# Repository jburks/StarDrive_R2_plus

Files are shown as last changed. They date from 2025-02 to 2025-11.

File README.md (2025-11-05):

# StarDrive_R2_plus
StarBoard SCSI Drive attachment with real-time clock

## Mini-FAQ:

### What is it?

StarDrive R2+ is an upgraded version of Chris "Crispy" Brenner's original reverse-engineered remake of the Microbotics StarDrive for their
StarBoard 2 expansion module for the Amiga 1000.

### Where can I get it?

This product is still in development. All files necessary for making your own will be here and links to assembled boards for sale will be
placed here when available.

### What's the status?

The original project has been converted to KiCAD and ports have been placed as accurately as possible using the materials still available
from Crispy's original design. Additional footprints for the slightly more available PCF8573T and footprints for a microcontroller and modern RTC are
WIP.

### What's this about an upgrade?

The original StarDrive uses two components that are no longer in production: the AM5380 SCSI interface controller; and the PCF8573P real-time clock.
Direct replacements are not known to be available for either, so StarBoard R2+ is planned to contain a microcontroller capable of emulating the PCF8573
so that a modern, easy to source solution is available. A substitute for the AM5380 has not been identified.

### How can I help?

The project would benefit from a modified StarBoard 2 driver that modifies the I2C code to talk to a modern RTC directly so that a PCF8573 or a
microcontroller that emulates one is not necessary.

## Board renderings

### Front:

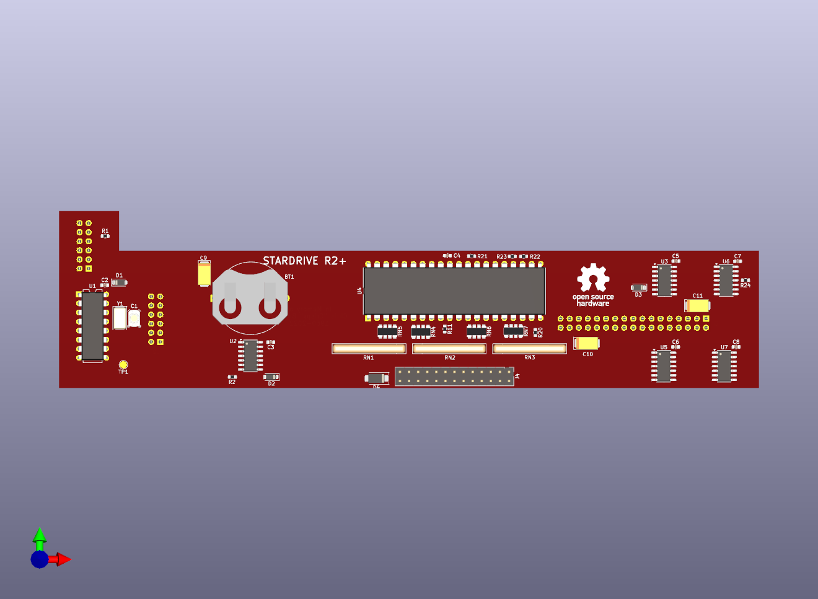
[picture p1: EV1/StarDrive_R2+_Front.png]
StarDrive R2+ Front


### Back:

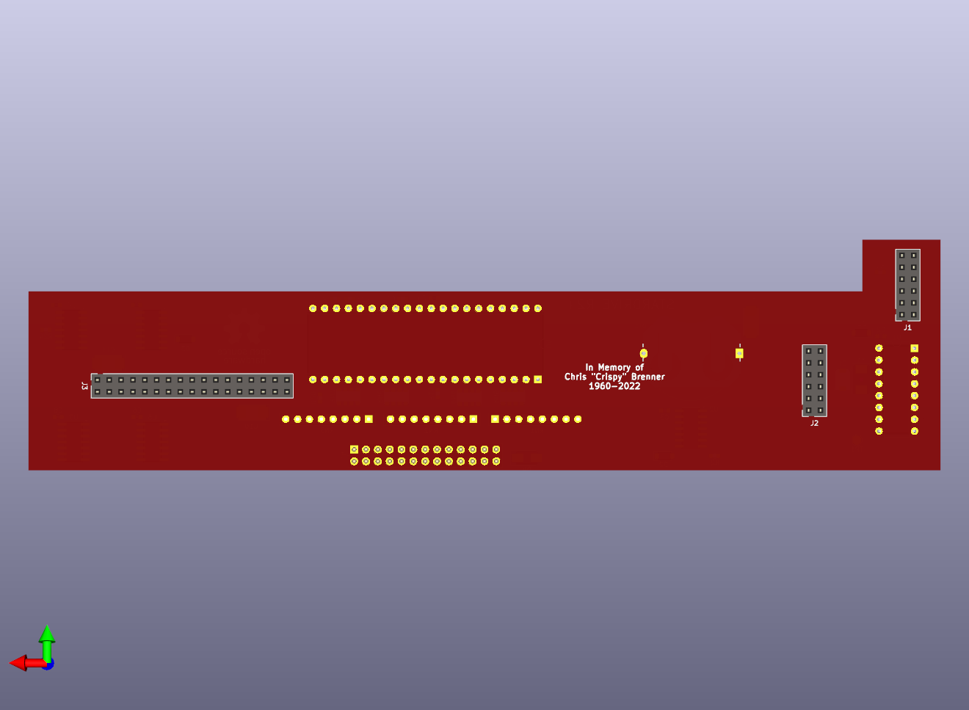
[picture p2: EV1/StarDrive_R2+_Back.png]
StarDrive R2+ Back


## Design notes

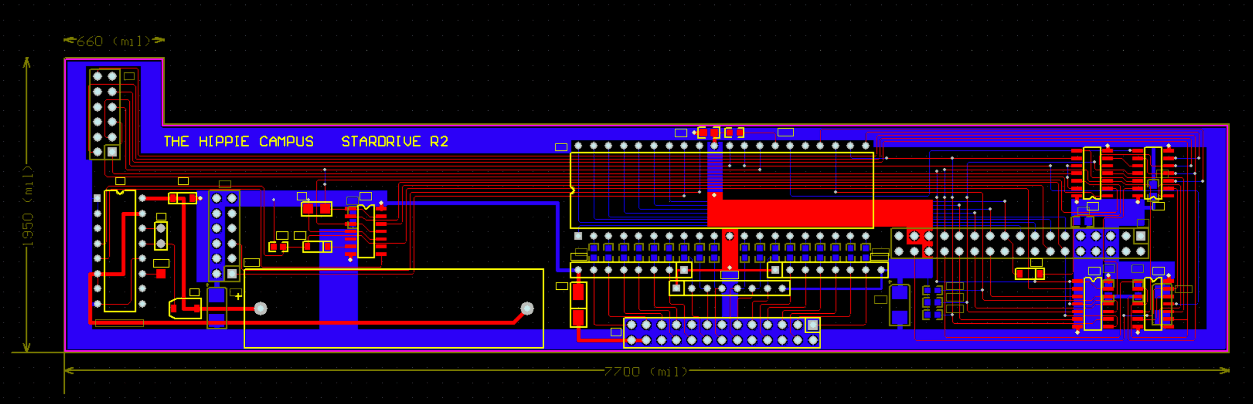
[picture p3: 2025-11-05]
X2_X2+_Overlay.gif

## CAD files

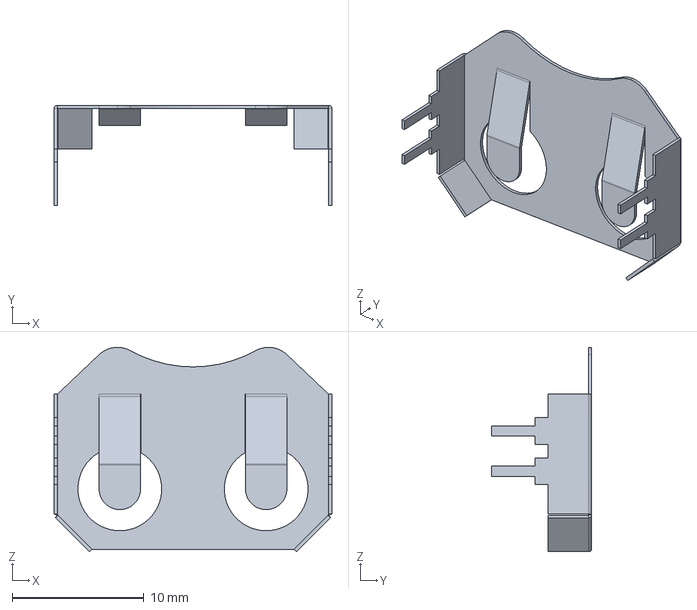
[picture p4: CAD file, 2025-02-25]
parts/3dmodels/c-bat-hld-001-thm-tr-b-3d.stp
21.1 x 7.62 x 15.5 mm

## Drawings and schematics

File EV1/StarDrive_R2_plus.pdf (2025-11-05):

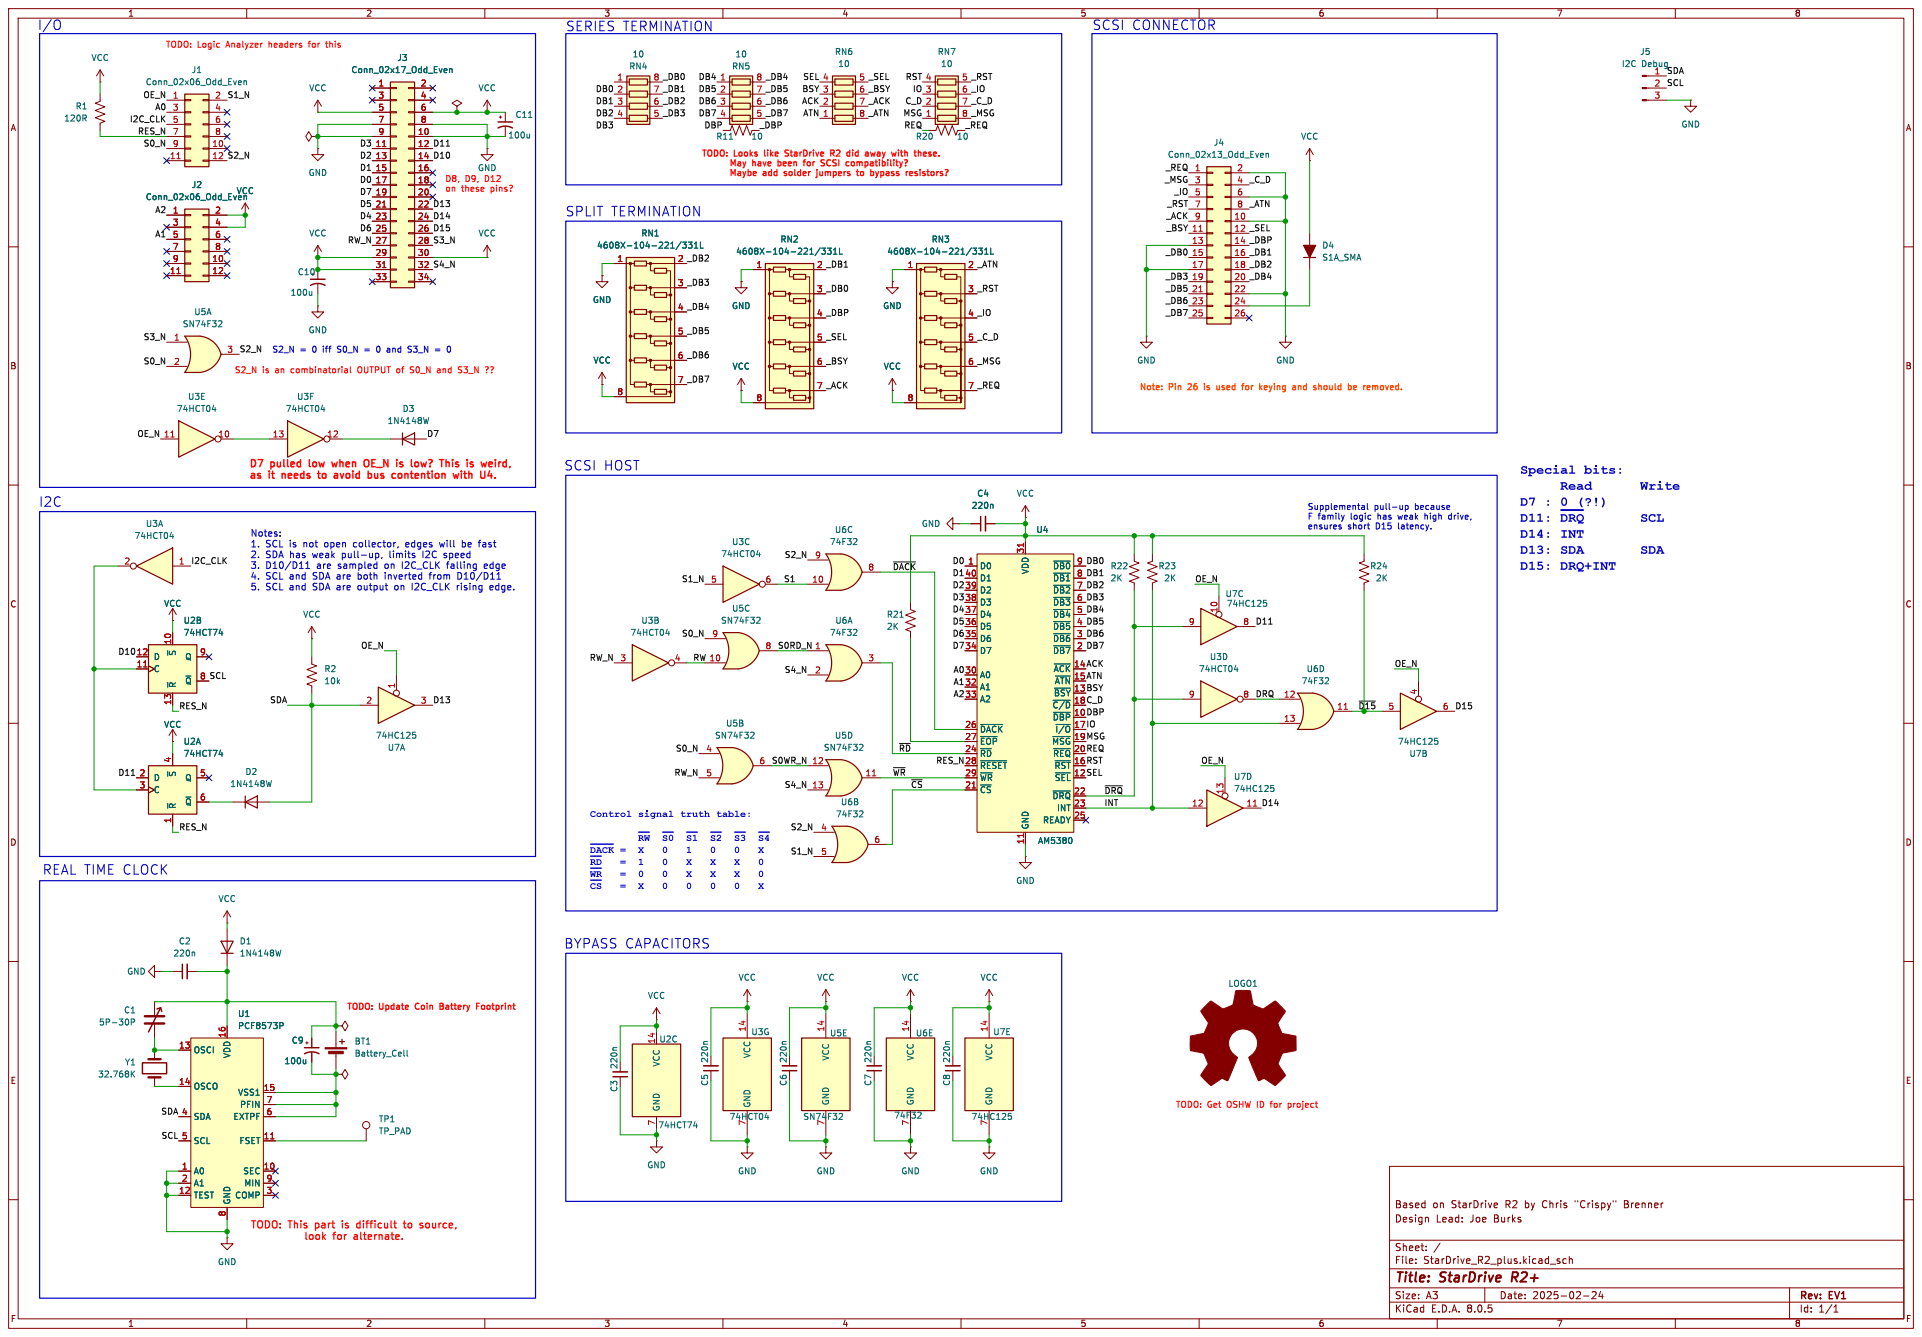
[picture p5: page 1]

TODO: Logic Analyzer headers for this

TODO: Looks like StarDrive R2 did away with these. May have been for SCSI compatibility?

4. SCL and SDA are both inverted from D10/D11
5. SCL and SDA are output on I2C_CLK rising edge.

Control signal truth table: ~{RW}~{S0}~{S1}~{S2}~{S3}~{S4}

TODO: Update Coin Battery Footprint

TODO: Get OSHW ID for project

TODO: This part is difficult to source,

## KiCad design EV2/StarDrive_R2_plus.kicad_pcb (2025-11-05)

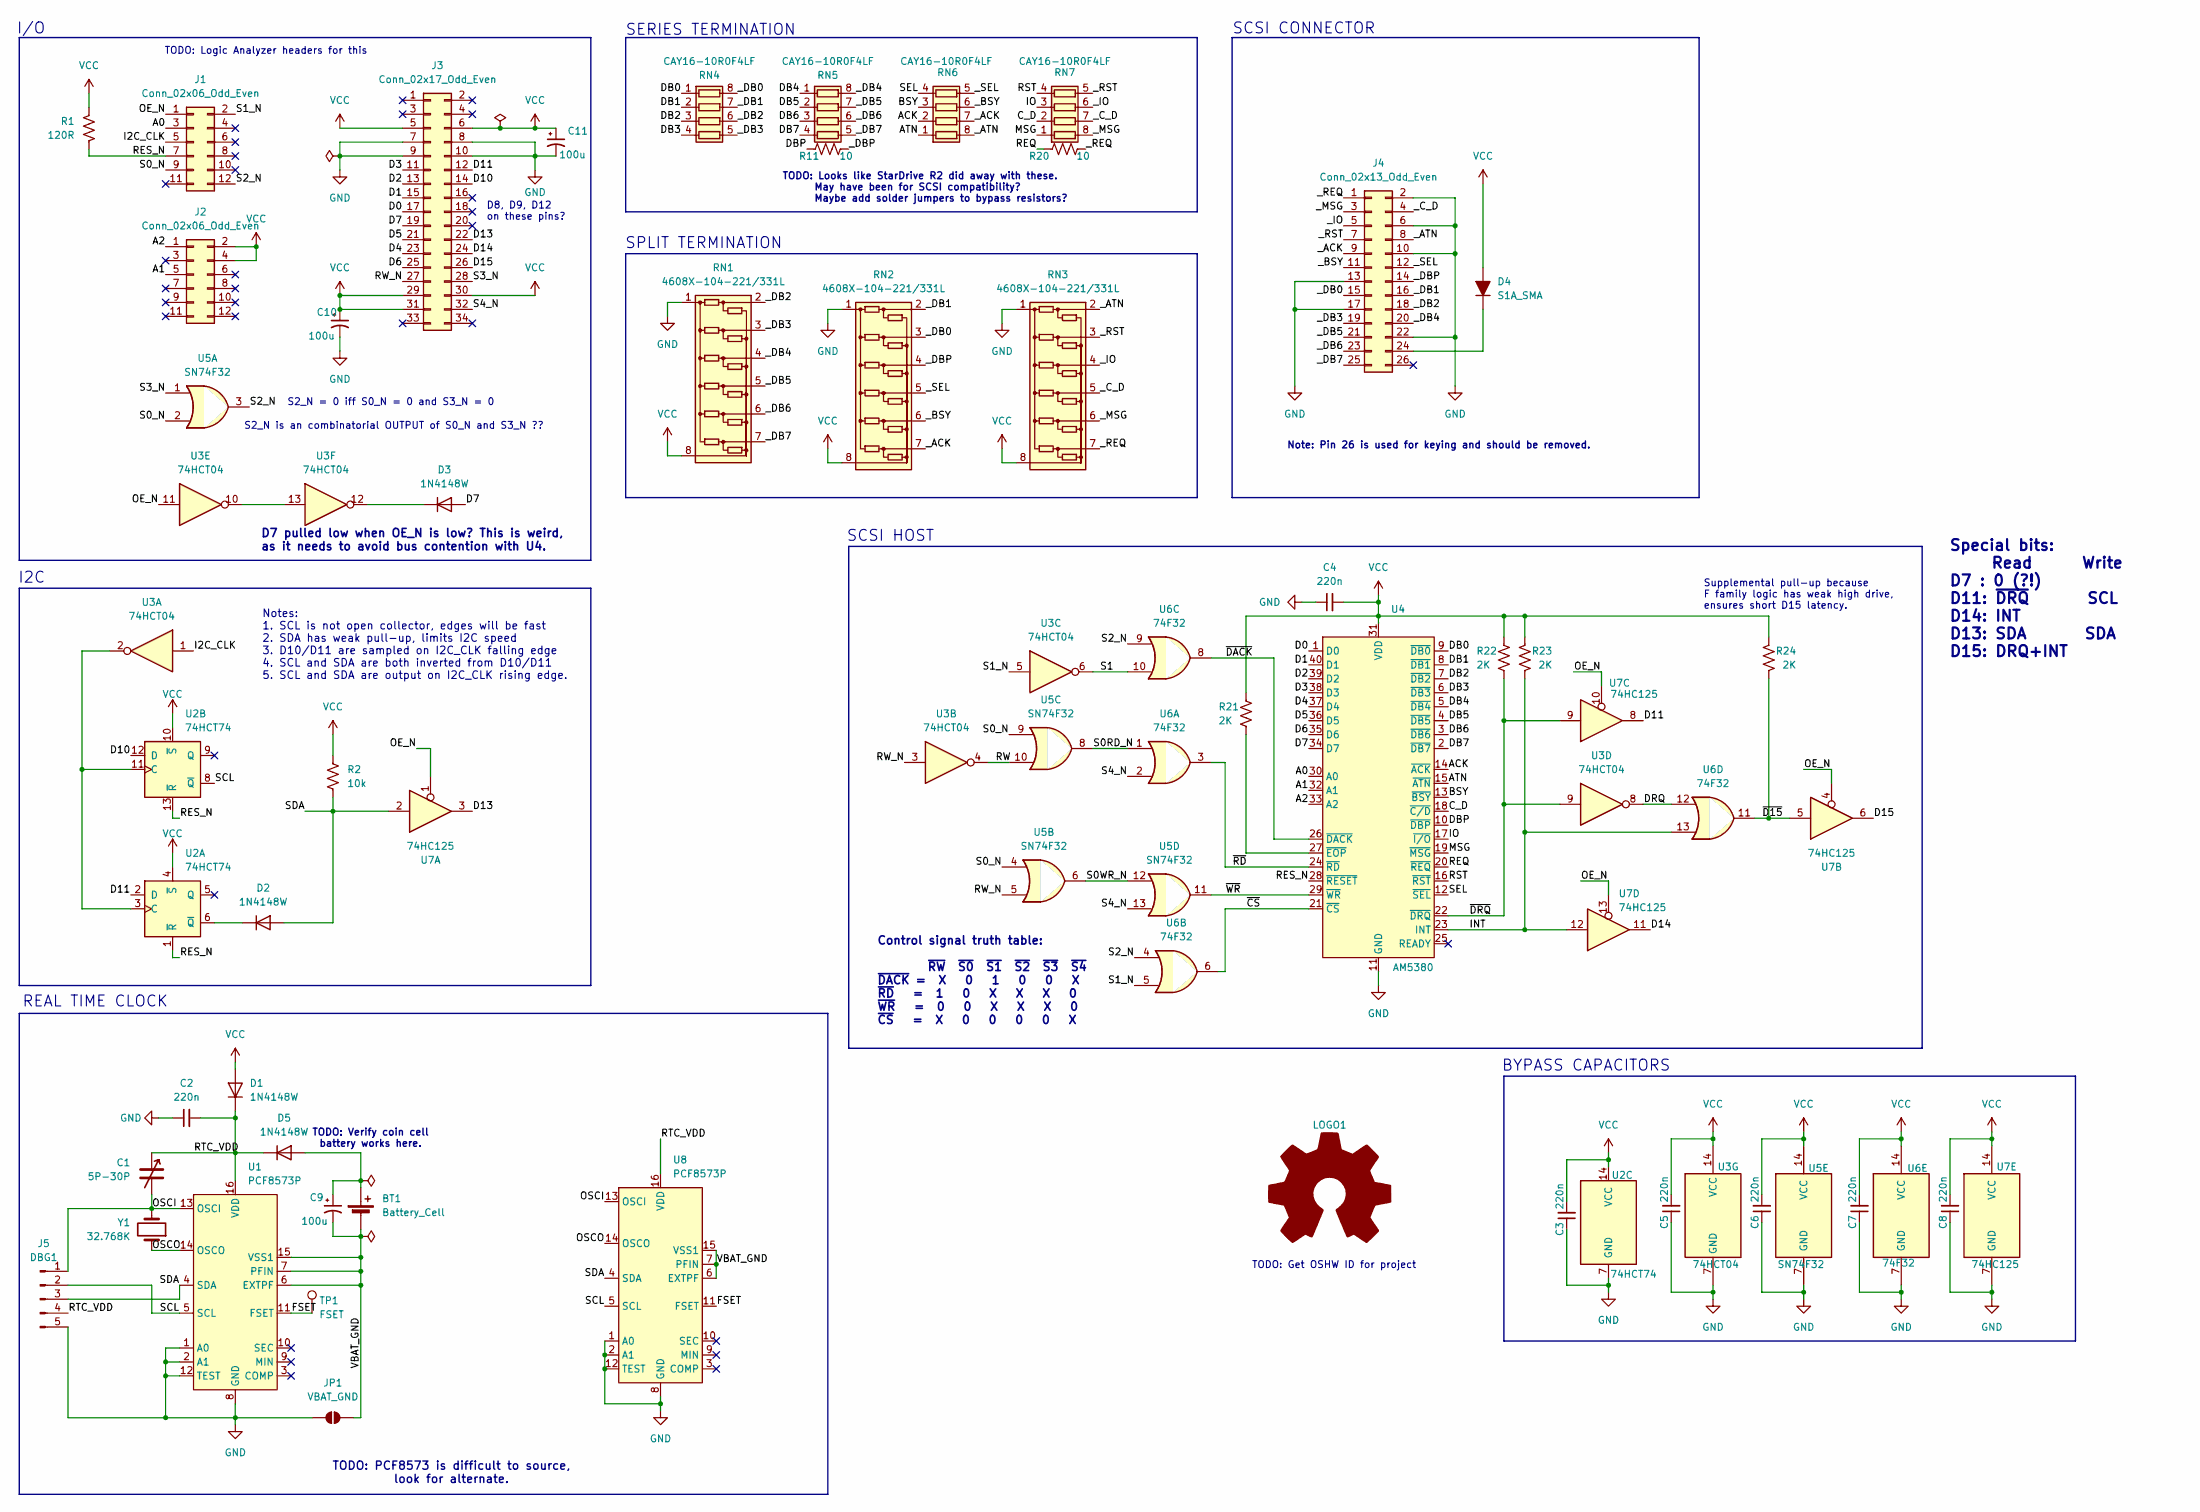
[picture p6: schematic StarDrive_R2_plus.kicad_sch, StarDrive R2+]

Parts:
BT1: Battery_Cell; AliEx_BatClip
C1: 5P-30P; C_Trimmer_Voltronics_JZ; Part JZ300
C2, C3, C4, C5, C6, C7, C8: 220n; C_0603_1608Metric
C9, C10, C11: 100u; CP_EIA-6032-15_Kemet-U
D1, D5: 1N4148W; D_SOD-123
D2, D3: 1N4148W; D_SOD-323_HandSoldering
D4: S1A_SMA; D_SMA
J1, J2: Conn_02x06_Odd_Even; PinSocket_2x06_P2.54mm_Vertical
J3: Conn_02x17_Odd_Even; PinSocket_2x17_P2.54mm_Vertical
J4: Conn_02x13_Odd_Even; PinHeader_2x13_P2.54mm_Vertical
J5: DBG1; PinHeader_1x05_P2.54mm_Vertical
JP1: VBAT_GND; SolderJumper-2_P1.3mm_Open_Pad1.0x1.5mm
LOGO1: Logo_Open_Hardware_Large; OSHW-Logo_11.4x12mm_SilkScreen
R1: 120R; R_0603_1608Metric
R2: 10k; R_0603_1608Metric
R11, R20: 10; R_0603_1608Metric
R21, R22, R23, R24: 2K; R_0603_1608Metric
RN1, RN2, RN3: 4608X-104-221/331L; R_Array_SIP8
RN4, RN5, RN6, RN7: CAY16-10R0F4LF; R_Array_Convex_4x0603
TP1: FSET; TestPoint_Pad_D2.0mm
U1: PCF8573P; DIP-16_W7.62mm
U2: 74HCT74; SO-14_3.9x8.65mm_P1.27mm
U3: 74HCT04; SOIC-14_3.9x8.7mm_P1.27mm
U4: AM5380; DIP-40_W15.24mm
U5: SN74F32; SOIC-14_3.9x8.7mm_P1.27mm
U6: 74F32; SOIC-14_3.9x8.7mm_P1.27mm
U7: 74HC125; SOIC-14_3.9x8.7mm_P1.27mm
U8: PCF8573P; SOIC-16W_7.5x10.3mm_P1.27mm
Y1: 32.768K; Crystal_SMD_3215-2Pin_3.2x1.5mm; Part CC7V-T1A-32.768kHz-12.5pF-20PPM-TC-QC

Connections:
/A0: J1.3, U4.30 (A0)
/A1: J2.5, U4.32 (A1)
/A2: J2.1, U4.33 (A2)
/ACK: RN6.2 (R2.1), U4.14 (~ACK)
/ATN: RN6.1 (R1.1), U4.15 (~ATN)
/BSY: RN6.3 (R3.1), U4.13 (~BSY)
/C_D: RN7.2 (R2.1), U4.18 (~C/D)
/D0: J3.17, U4.1 (D0)
/D1: J3.15, U4.40 (D1)
/D2: J3.13, U4.39 (D2)
/D3: J3.11, U4.38 (D3)
/D4: J3.23, U4.37 (D4)
/D5: J3.21, U4.36 (D5)
/D6: J3.25, U4.35 (D6)
/D7: D3.2 (A), J3.19, U4.34 (D7)
/D10: J3.14, U2.12 (D)
/D11: J3.12, U2.2 (D), U7.8
/D13: J3.22, U7.3
/D14: J3.24, U7.11
/D15: J3.26, U7.6
/DB0: RN4.1 (R1.1), U4.9 (~DB0)
/DB1: RN4.2 (R2.1), U4.8 (~DB1)
/DB2: RN4.3 (R3.1), U4.7 (~DB2)
/DB3: RN4.4 (R4.1), U4.6 (~DB3)
/DB4: RN5.1 (R1.1), U4.5 (~DB4)
/DB5: RN5.2 (R2.1), U4.4 (~DB5)
/DB6: RN5.3 (R3.1), U4.3 (~DB6)
/DB7: RN5.4 (R4.1), U4.2 (~DB7)
/DBP: R11.1, U4.10 (~DBP)
/DRQ: U3.8, U6.12
/FSET: TP1.1, U1.11 (FSET), U8.11 (FSET)
/I2C_CLK: J1.5, U3.1
/INT: R23.2, U4.23 (INT), U6.13, U7.12
/IO: RN7.3 (R3.1), U4.17 (~I/O)
/MSG: RN7.1 (R1.1), U4.19 (~MSG)
/OE_N: J1.1, U3.11, U7.1, U7.4, U7.10, U7.13
/OSCI: C1.2, J5.1, U1.13 (OSCI), U8.13 (OSCI), Y1.2
/OSCO: U1.14 (OSCO), U8.14 (OSCO), Y1.1
/REQ: R20.1, U4.20 (~REQ)
/RES_N: J1.7, R1.1, U2.1 (~R), U2.13 (~R), U4.28 (~RESET)
/RST: RN7.4 (R4.1), U4.16 (~RST)
/RTC_VDD: C1.1, C2.2, D1.1 (K), D5.1 (K), J5.4, U1.16 (VDD), U8.16 (VDD)
/RW: U3.4, U5.10
/RW_N: J3.27, U3.3, U5.5
/S0RD_N: U5.8, U6.1
/S0WR_N: U5.6, U5.12
/S0_N: J1.9, U5.2, U5.4, U5.9
/S1: U3.6, U6.10
/S1_N: J1.2, U3.5, U6.5
/S2_N: J1.12, U5.3, U6.4, U6.9
/S3_N: J3.28, U5.1
/S4_N: J3.32, U5.13, U6.2
/SCL: J5.2, U1.5 (SCL), U2.8 (~Q), U8.5 (SCL)
/SDA: D2.2 (A), J5.3, R2.2, U1.4 (SDA), U7.2, U8.4 (SDA)
/SEL: RN6.4 (R4.1), U4.12 (~SEL)
/VBAT_GND: BT1.2 (-), C9.2, JP1.2 (B), U1.6 (EXTPF), U1.7 (PFIN), U1.15 (VSS1), U8.6 (EXTPF), U8.7 (PFIN), U8.15 (VSS1)
/_ACK: J4.9, RN2.7 (R6), RN6.7 (R2.2)
/_ATN: J4.8, RN3.2 (R1), RN6.8 (R1.2)
/_BSY: J4.11, RN2.6 (R5), RN6.6 (R3.2)
/_C_D: J4.4, RN3.5 (R4), RN7.7 (R2.2)
/_DB0: J4.15, RN2.3 (R2), RN4.8 (R1.2)
/_DB1: J4.16, RN2.2 (R1), RN4.7 (R2.2)
/_DB2: J4.18, RN1.2 (R1), RN4.6 (R3.2)
/_DB3: J4.19, RN1.3 (R2), RN4.5 (R4.2)
/_DB4: J4.20, RN1.4 (R3), RN5.8 (R1.2)
/_DB5: J4.21, RN1.5 (R4), RN5.7 (R2.2)
/_DB6: J4.23, RN1.6 (R5), RN5.6 (R3.2)
/_DB7: J4.25, RN1.7 (R6), RN5.5 (R4.2)
/_DBP: J4.14, R11.2, RN2.4 (R3)
/_IO: J4.5, RN3.4 (R3), RN7.6 (R3.2)
/_MSG: J4.3, RN3.6 (R5), RN7.8 (R1.2)
/_REQ: J4.1, R20.2, RN3.7 (R6)
/_RST: J4.7, RN3.3 (R2), RN7.5 (R4.2)
/_SEL: J4.12, RN2.5 (R4), RN6.5 (R4.2)
/~CS: U4.21 (~CS), U6.6
/~D15: R24.2, U6.11, U7.5
/~DACK: U4.26 (~DACK), U6.8
/~DRQ: R22.2, U3.9, U4.22 (~DRQ), U7.9
/~RD: U4.24 (~RD), U6.3
/~WR: U4.29 (~WR), U5.11
GND: C2.1, C3.1, C4.1, C5.1, C6.1, C7.1, C8.1, C10.2, C11.2, J3.7, J3.8, J3.9, J3.10, J4.2, J4.6, J4.10, J4.13, J4.17, J4.22, J5.5, JP1.1 (A), RN1.1 (COM1), RN2.1 (COM1), RN3.1 (COM1), U1.1 (A0), U1.2 (A1), U1.8 (GND), U1.12 (TEST), U2.7 (GND), U3.7 (GND), U4.11 (GND), U5.7 (GND), U6.7 (GND), U7.7 (GND), U8.1 (A0), U8.2 (A1), U8.8 (GND), U8.12 (TEST)
unnamed: BT1.1 (+), C9.1, D5.2 (A)
unnamed: D2.1 (K), U2.6 (~Q)
unnamed: D3.1 (K), U3.12
unnamed: D4.1 (K), J4.24
unnamed: U2.3 (C), U2.11 (C), U3.2
unnamed: U3.10, U3.13
unnamed: R21.2, U4.27 (~EOP)
VCC: C3.2, C4.2, C5.2, C6.2, C7.2, C8.2, C10.1, C11.1, D1.2 (A), D4.2 (A), J2.2, J2.4, J3.5, J3.6, J3.29, J3.30, J3.31, R1.2, R2.1, R21.1, R22.1, R23.1, R24.1, RN1.8 (COM2), RN2.8 (COM2), RN3.8 (COM2), U2.4 (~S), U2.10 (~S), U2.14 (VCC), U3.14 (VCC), U4.31 (VDD), U5.14 (VCC), U6.14 (VCC), U7.14 (VCC)

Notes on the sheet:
TODO: Verify coin cell battery works here.
I/O
TODO: Get OSHW ID for project
D7 pulled low when OE_N is low? This is weird, as it needs to avoid bus contention with U4.
Special bits: Read Write D7 : 0 (?!) D11: ~{DRQ} SCL D14: INT D13: SDA SDA D15: DRQ+INT
BYPASS CAPACITORS
S2_N = 0 iff S0_N = 0 and S3_N = 0
REAL TIME CLOCK
SCSI HOST
TODO: Logic Analyzer headers for this
Supplemental pull-up because F family logic has weak high drive, ensures short D15 latency.
D8, D9, D12 on these pins?
I2C
TODO: PCF8573 is difficult to source, look for alternate.
Control signal truth table: ~{RW} ~{S0} ~{S1} ~{S2} ~{S3} ~{S4} ~{DACK} = X 0 1 0 0 X ~{RD} = 1 0 X X X 0 ~{WR} = 0 0 X X X 0 ~{CS} = X 0 0 0 0 X
SCSI CONNECTOR
SPLIT TERMINATION
Note: Pin 26 is used for keying and should be removed.
SERIES TERMINATION
TODO: Looks like StarDrive R2 did away with these. May have been for SCSI compatibility? Maybe add solder jumpers to bypass resistors?
Notes: 1. SCL is not open collector, edges will be fast 2. SDA has weak pull-up, limits I2C speed 3. D10/D11 are sampled on I2C_CLK falling edge 4. SCL and SDA are both inverted from D10/D11 5. SCL and SDA are output on I2C_CLK rising edge.
S2_N is an combinatorial OUTPUT of S0_N and S3_N ??

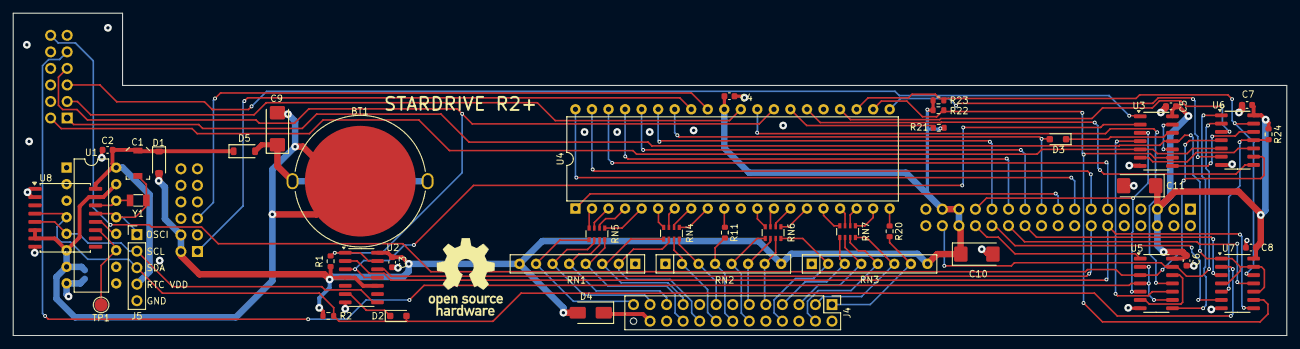
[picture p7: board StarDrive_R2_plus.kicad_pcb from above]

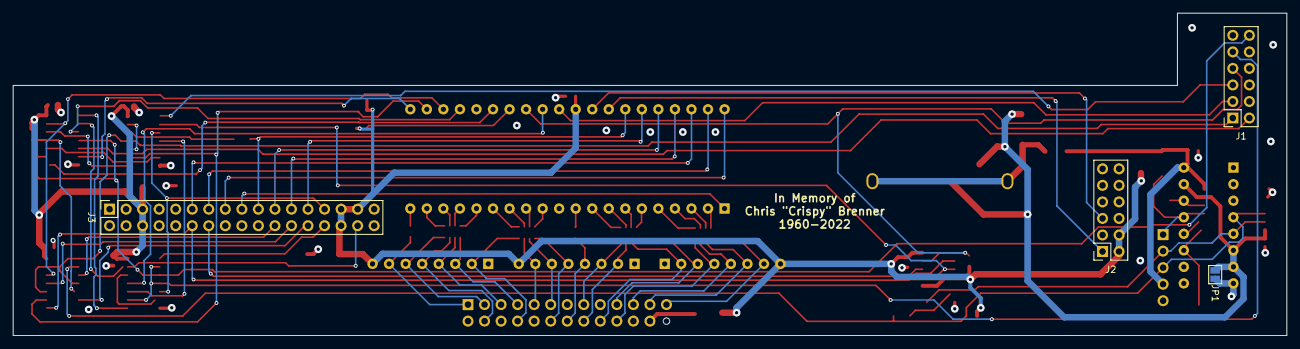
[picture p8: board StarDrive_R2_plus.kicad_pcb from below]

Board: 4 copper layers, 195.6 x 49.5 mm, 49 parts (4 on the bottom side), 89 nets.

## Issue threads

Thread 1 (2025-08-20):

Request for an interim solution

idun-project, 2025-08-20:
Hi. Great to see you have resurrected this project!

I understand your ambitions as far as updating the legacy ICs and the software driver. Not knowing your timeline for that, is it reasonable to ask for an interim solution IF I can obtain the SCSI controller and RTC? I found both on eBay.

Best I can tell, your design just needs the PCB routing to be done to be ready-to-go with the legacy ICs. I'm happy to take a crack at doing that, and then I can build/test and let you know whether it worked. Potentially you could pull the changes into a separate branch here.

Please let me know your thoughts.

Best.

jburks, 2025-08-21:
Looks like I had not pushed changes in some time. The EV1 branch has the routed PCB that I've had made.

Closed 2025-09-30.

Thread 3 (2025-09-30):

[EV1] Resistor array footprints don't match parts

jburks, 2025-09-30:
For some reason the KiCAD footprint for these resistor arrays does not match components of that size. These should be replaced with a footprint of a resistor array that is easy to source and easy to place by hand.

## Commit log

2025-02-25 Initial EV1 commit
    [StarDrive_R2_plus.kicad_pcb, StarDrive_R2_plus.kicad_sch, c-bat-hld-001-thm-tr-b-3d.stp]
2025-02-25 Added notes and comments to schematic Added schematic plot
    [StarDrive_R2_plus.kicad_sch]
2025-03-28 Updated header locations
    [StarDrive_R2_plus.kicad_pcb, StarDrive_R2_plus.kicad_sch]
2025-08-21 First prototype Gerber out
    [StarDrive_R2_plus.kicad_pcb, StarDrive_R2_plus.kicad_sch]
2025-11-05 Create EV2 folder
    [StarDrive_R2_plus.kicad_pcb, StarDrive_R2_plus.kicad_sch]
2025-11-05 Fix #3 #4
    [StarDrive_R2_plus.kicad_pcb, StarDrive_R2_plus.kicad_sch]
